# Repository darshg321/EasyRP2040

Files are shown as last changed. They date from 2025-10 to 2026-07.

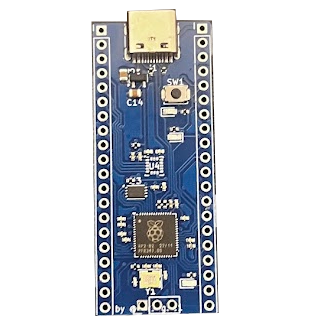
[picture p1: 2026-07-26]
BUILD.png

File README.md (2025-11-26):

# EasyRP2040.csv

my custom rp2040 devboard :)

has debug leds and a 9-DOF IMU composed of multiple 3-axis sensors

in the format of a rpi pico



# BOM

|Id |Designator|Footprint |Quantity |Comment |Supplier and ref|
|---|---|---|---|---|---|
|1  |R5,R7 |R_0402_1005Metric |2 |1K | |
|2  |C16,C15 |C_0402_1005Metric |2 |33pF | |
|3  |C10,C11,C5,C8,C3,C2,C7,C6,C4,C17,C1,C20,C18|C_0402_1005Metric |13 |0.1uF | |
|4  |D3,D1,D2  |LED_0603_1608Metric |3 |LED | |
|5  |Y1 |Crystal_SMD_3225-4Pin_3.2x2.5mm |1 |12MHz | |
|6  |R10,R9,R8 |R_0402_1005Metric |3 |680 | |
|7  |J4 |PinHeader_1x03_P2.54mm_Vertical |1 |Conn_01x03 | |
|8  |C9,C12 |C_0402_1005Metric |2 |1uF | |
|9  |U1 |QFN-56-1EP_7x7mm_P0.4mm_EP3.2x3.2mm |1 |RP2040 | |
|10 |R4,R3 |R_0402_1005Metric |2 |27 | |
|11 |U3 |Winbond_USON-8-1EP_3x2mm_P0.5mm_EP0.2x1.6mm|1 |W25Q128JVS | |
|12 |J3,J2 |PinHeader_1x20_P2.54mm_Vertical |2 |Conn_01x20 | |
|13 |C21 |C_0402_1005Metric |1 |2.2uF | |
|14 |C13,C14 |C_0201_0603Metric |2 |10uF | |
|15 |U4 |LGA-16_3x3mm_P0.5mm_LayoutBorder3x5y |1 |ICM-20602 | |
|16 |U2 |SOT-23 |1 |MCP1700x-330xxTT | |
|17 |J1 |USB_C_Receptacle_HRO_TYPE-C-31-M-12 |1 |USB_C_Receptacle_USB2.0_14P| |
|18 |SW1 |SW_Push_SPST_NO_Alps_SKRK |1 |SW_Push | |
|19 |R6 |R_0402_1005Metric |1 |10K | |
|20 |R2,R1 |R_0402_1005Metric |2 |5.1K | |
|21 |C19 |C_0402_1005Metric |1 |10nF | |

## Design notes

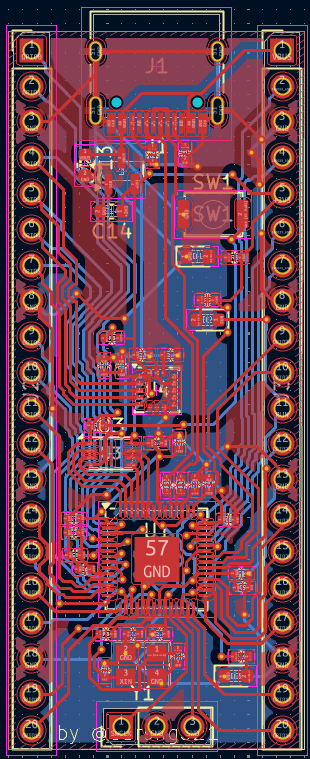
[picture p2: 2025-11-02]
EasyRP2040.png

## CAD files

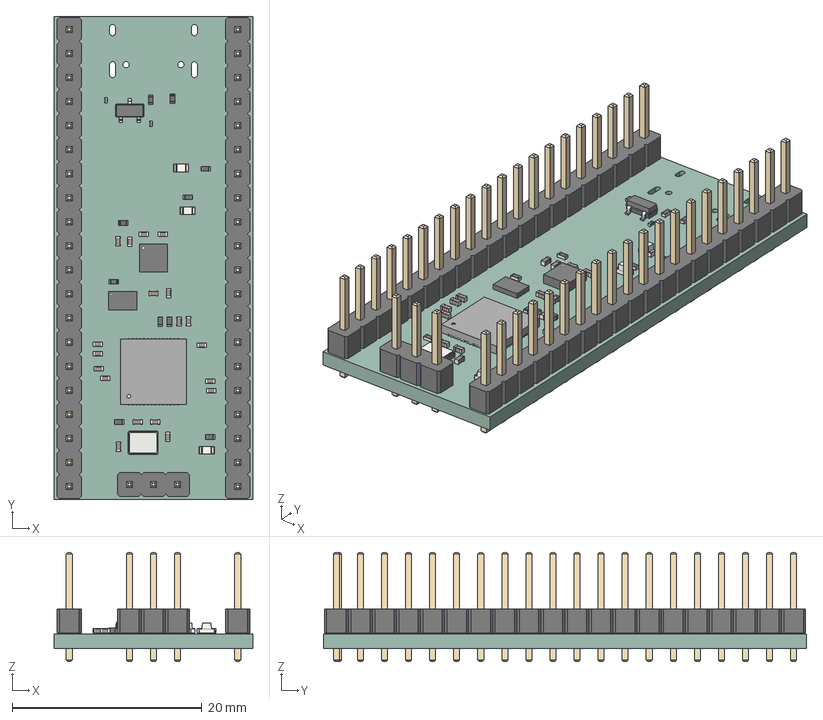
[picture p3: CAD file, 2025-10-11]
EasyRP2040.step
21.0 x 51.0 x 11.5 mm
C_0402_1005Metric x 19
PinHeader_1x20_P2.54mm_Vertical x 2
R_0402_1005Metric x 10
LED_0603_1608Metric x 3
C_0201_0603Metric x 2
LGA-16_3x3mm_P0.5mm_LayoutBorder3x5y
SOT-23
QFN-56-1EP_7x7mm_P0.4mm_EP3.2x3.2mm
Winbond_USON-8-1EP_3x2mm_P0.5mm_EP0.2x1.6mm
Crystal_SMD_3225-4Pin_3.2x2.5mm
PinHeader_1x03_P2.54mm_Vertical
EasyRP2040_PCB

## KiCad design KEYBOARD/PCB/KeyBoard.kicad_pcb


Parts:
A1: RaspberryPi_Pico; RaspberryPi_Pico_Common_Unspecified
D1, D2, D3, D4, D5, D6, D7, D8, D9, D10, D11, D12, D13, D14, D15, D16, D17, D18, D19, D20, D21, D22, D23, D24, D25, D26, D27, D28, D29, D30, D31, D32, D33, D34, D35, D36, D37, D38, D39, D40, D41, D42, D43, D44, D45, D46, D47, D48, D49, D50, D51, D52, D53, D54, D55, D56, D57, D58, D59, D60, D61: 1N4148; D_DO-35_SOD27_P7.62mm_Horizontal
S1: MX_stab; STAB_MX_2u
S2, S3: MX_stab; STAB_MX_2.25u
S4: MX_stab; STAB_MX_2.75u
S5: MX_stab; STAB_MX_6.25u
SW1, SW2, SW3, SW4, SW5, SW6, SW7, SW8, SW9, SW10, SW11, SW12, SW13, SW16, SW17, SW18, SW19, SW20, SW21, SW22, SW23, SW24, SW25, SW26, SW27, SW30, SW31, SW32, SW33, SW34, SW35, SW36, SW37, SW38, SW39, SW40, SW51, SW52, SW53, SW54, SW55, SW56, SW57, SW58, SW59, SW60: SW_Push; SW_Cherry_MX_1.00u_PCB
SW14: SW_Push; SW_Cherry_MX_2.00u_PCB
SW15: SW_Push; SW_Cherry_MX_1.50u_PCB
SW28: SW_Push; SW_Cherry_MX_1.50u_Plate
SW29: SW_Push; SW_Cherry_MX_1.75u_PCB
SW41, SW50: SW_Push; SW_Cherry_MX_2.25u_PCB
SW42, SW43, SW44, SW46, SW48, SW49: SW_Push; SW_Cherry_MX_1.25u_PCB
SW45: SW_Push; SW_Cherry_MX_6.25u_PCB
SW47: SW_Push; SW_Cherry_MX_1.25u_Plate
SW61: SW_Push; SW_Cherry_MX_2.75u_PCB
SW62, SW63: RotaryEncoder_Switch_MP; RotaryEncoder_Alps_EC11E-Switch_Vertical_H20mm

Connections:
A1: A1.27 (GPIO21), SW62.A
A2: A1.32 (GPIO27_ADC1), SW63.A
B1: A1.29 (GPIO22), SW62.B
B2: A1.34 (GPIO28_ADC2), SW63.B
C0: A1.10 (GPIO7), SW1.1, SW15.1, SW29.1, SW42.1, SW50.1
C1: A1.11 (GPIO8), SW2.1, SW16.1, SW30.1, SW43.1, SW51.1
C2: A1.12 (GPIO9), SW3.1, SW17.1, SW31.1, SW44.1, SW52.1
C3: A1.14 (GPIO10), SW4.1, SW18.1, SW32.1, SW53.1
C4: A1.15 (GPIO11), SW5.1, SW19.1, SW33.1, SW54.1
C5: A1.16 (GPIO12), SW6.1, SW20.1, SW34.1, SW45.1, SW55.1
C6: A1.17 (GPIO13), SW7.1, SW21.1, SW35.1, SW56.1
C7: A1.19 (GPIO14), SW8.1, SW22.1, SW36.1, SW57.1
C8: A1.20 (GPIO15), SW9.1, SW23.1, SW37.1, SW46.1, SW58.1
C9: A1.21 (GPIO16), SW10.1, SW24.1, SW38.1, SW47.1, SW59.1
C10: A1.22 (GPIO17), SW11.1, SW25.1, SW39.1, SW48.1, SW60.1
C11: A1.24 (GPIO18), SW12.1, SW26.1, SW40.1, SW49.1, SW61.1
C12: A1.25 (GPIO19), SW13.1, SW27.1, SW41.1
C13: A1.26 (GPIO20), SW14.1, SW28.1
GND: A1.33 (AGND), SW62.C, SW62.S2, SW63.C, SW63.S2
unnamed: A1.3 (GND), A1.8 (GND), A1.13 (GND), A1.18 (GND), A1.23 (GND), A1.28 (GND), A1.38 (GND)
unnamed: D1.2 (A), SW1.2
unnamed: D2.2 (A), SW2.2
unnamed: D3.2 (A), SW3.2
unnamed: D4.2 (A), SW4.2
unnamed: D5.2 (A), SW5.2
unnamed: D6.2 (A), SW6.2
unnamed: D7.2 (A), SW7.2
unnamed: D8.2 (A), SW8.2
unnamed: D9.2 (A), SW9.2
unnamed: D10.2 (A), SW10.2
unnamed: D11.2 (A), SW11.2
unnamed: D12.2 (A), SW12.2
unnamed: D13.2 (A), SW13.2
unnamed: D14.2 (A), SW14.2
unnamed: D15.2 (A), SW15.2
unnamed: D16.2 (A), SW16.2
unnamed: D17.2 (A), SW17.2
unnamed: D18.2 (A), SW18.2
unnamed: D19.2 (A), SW19.2
unnamed: D20.2 (A), SW20.2
unnamed: D21.2 (A), SW21.2
unnamed: D22.2 (A), SW22.2
unnamed: D23.2 (A), SW23.2
unnamed: D24.2 (A), SW24.2
unnamed: D25.2 (A), SW25.2
unnamed: D26.2 (A), SW26.2
unnamed: D27.2 (A), SW27.2
unnamed: D28.2 (A), SW28.2
unnamed: D29.2 (A), SW29.2
unnamed: D30.2 (A), SW30.2
unnamed: D31.2 (A), SW31.2
unnamed: D32.2 (A), SW32.2
unnamed: D33.2 (A), SW33.2
unnamed: D34.2 (A), SW34.2
unnamed: D35.2 (A), SW35.2
unnamed: D36.2 (A), SW36.2
unnamed: D37.2 (A), SW37.2
unnamed: D38.2 (A), SW38.2
unnamed: D39.2 (A), SW39.2
unnamed: D40.2 (A), SW40.2
unnamed: D41.2 (A), SW41.2
unnamed: D42.2 (A), SW42.2
unnamed: D43.2 (A), SW43.2
unnamed: D44.2 (A), SW44.2
unnamed: D45.2 (A), SW45.2
unnamed: D46.2 (A), SW46.2
unnamed: D47.2 (A), SW47.2
unnamed: D48.2 (A), SW48.2
unnamed: D49.2 (A), SW49.2
unnamed: D50.2 (A), SW50.2
unnamed: D51.2 (A), SW51.2
unnamed: D52.2 (A), SW52.2
unnamed: D53.2 (A), SW53.2
unnamed: D54.2 (A), SW54.2
unnamed: D55.2 (A), SW55.2
unnamed: D56.2 (A), SW56.2
unnamed: D57.2 (A), SW57.2
unnamed: D58.2 (A), SW58.2
unnamed: D59.2 (A), SW59.2
unnamed: D60.2 (A), SW60.2
unnamed: D61.2 (A), SW61.2
R0: A1.4 (GPIO2), D1.1 (K), D2.1 (K), D3.1 (K), D4.1 (K), D5.1 (K), D6.1 (K), D7.1 (K), D8.1 (K), D9.1 (K), D10.1 (K), D11.1 (K), D12.1 (K), D13.1 (K), D14.1 (K)
R1: A1.5 (GPIO3), D15.1 (K), D16.1 (K), D17.1 (K), D18.1 (K), D19.1 (K), D20.1 (K), D21.1 (K), D22.1 (K), D23.1 (K), D24.1 (K), D25.1 (K), D26.1 (K), D27.1 (K), D28.1 (K)
R2: A1.6 (GPIO4), D29.1 (K), D30.1 (K), D31.1 (K), D32.1 (K), D33.1 (K), D34.1 (K), D35.1 (K), D36.1 (K), D37.1 (K), D38.1 (K), D39.1 (K), D40.1 (K), D41.1 (K)
R3: A1.7 (GPIO5), D50.1 (K), D51.1 (K), D52.1 (K), D53.1 (K), D54.1 (K), D55.1 (K), D56.1 (K), D57.1 (K), D58.1 (K), D59.1 (K), D60.1 (K), D61.1 (K)
R4: A1.9 (GPIO6), D42.1 (K), D43.1 (K), D44.1 (K), D45.1 (K), D46.1 (K), D47.1 (K), D48.1 (K), D49.1 (K)
S1: A1.31 (GPIO26_ADC0), SW62.S1
S2: A1.2 (GPIO1), SW63.S1



Board: 2 copper layers, 321.0 x 101.0 mm, 130 parts (61 on the bottom side), 88 nets.

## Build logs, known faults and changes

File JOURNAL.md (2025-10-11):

<!--
  ===================    !!READ THIS NOTICE!!   ====================
  DO NOT edit this file manually. Your changes WILL BE OVERWRITTEN!
  This journal is auto generated and updated by Hack Club Blueprint.
  To edit this file, please edit your journal entries on Blueprint.
  ==================================================================
-->

This is my journal of the design and building process of **EasyRP2040**.  
You can view this journal in more detail on **Hack Club Blueprint** [here](https://blueprint.hackclub.com/projects/391).

## 10/10/2025 4 PM - finished the schamtic !  

finished the schematic for the devboard

notes on learning:

- decoupling capacitors filter out noise in power; 0.1uF for the each power pin (theres multiple in reality, kicad just merges the same ones together), and 1uF for each power line
- shield is the metal conductive part on the usb, connects to gnd to improve EMI (electromagnetic interference)
- 10uF bulk capacitors to filter out significant noise when 5v is stepped down to 3v3, both on input and output
- usb dp and dm go through 27ohm resistors to prevent distortion at high data speed, called termination resistors
- crystal oscillator: vibrating quartz crystal, amplified and fed to the MCU, this acts as a clock for all the other digital peripherals
- important here bc using usb c; data needs to come in at very specific times
- needs to be physically very close to the MCU
- XIN: output from crystal to MCU
- XOUT: output from MCU to crystal to control
- damping resistor to XOUT for signal integrity
- series capacitors (external load) for crystal to resonate at correct frequency
- SPI pins: MOSI (master output), MISO (master input), SCLK (crystal oscillator timing), SS/CS (device selection, add more of these for more devices)
- using quad SPI with this, but has 4 IO for 4x data transferring
- needs to be connected to the dedicated hardware controller (QSPI) on the MCU
- booting: if QSPI SS is GND when booting up, it goes into BOOTSEL, which is when it appears as a usb device
- done by adding a pull up resistor (guarantee HIGH when booting) to 3v3, and a resistor (limit current to pin) to a button that goes to GND

Screenshot 2025-10-10 165033.png

## 10/10/2025 7 PM - added imu + leds for customization  

added the icm-20602 imu on the devboard; picked it bc its the simplest one that jlcpcb has. it requires two capacitors on vdd for some reason, and one other one on vddio. also added leds, one is a power led (will be green), one is a bootloader led which hopefully going through RUN should only be on when the devboard is in BOOTSEL, and one last one thats just connected to gpio25 bc its unused.
Screenshot 2025-10-10 190902.png  

## 10/10/2025 10 PM - partially routed pcb  

added footprints to everything, and partially routed the pcb. i have the rough shape of everything there, and roughly where everything is supposed to go. learned that you need to do differential pairs, and that the usb lines need to be the same length so that data travel at the same exact rate
Screenshot 2025-10-10 224958.png

## 10/11/2025 1 AM - more routing...  

this takes forever aaaa
routed more of the pcb, started the gnd plane which didnt do much bc my routing was very bad, separated a whole bunch of gnd pins. need to fix a lot of routing bc i have a bunch of bottom and top traces so i cant pass gnd through it :(
Screenshot 2025-10-11 010821.png  

## 10/11/2025 4 PM - finished routing the pcb  

finished routing the pcb; took forever to fix my routing but oh well.
lessons learned: 
- do ics first
- do capacitors after that
- minimize vias and non gnd back signals better
i have some thermal via issues but that isnt a big problem, especially single im doing pcba as well
Screenshot 2025-10-11 163931.png

## 10/11/2025 7 PM - added to jlcpcb cart  

took forever too but finished making the prod files and fixing everything on jlcpcb

unfortunately the imu i put is standard only, and that adds like $50, so ill buy it and place it myself since i have solder paste and a hot gun

also drew silkscreen stuff which i didnt mention; made it on excalidraw i think it looks cute :)
done yippee



Screenshot 2025-10-11 192141.png

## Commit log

2025-10-10 finished schematic
    [EasyRP2040.kicad_sch]
2025-10-10 added imu + leds to schematic
    [EasyRP2040.kicad_sch]
2025-10-22 fixed c13 c14
    [EasyRP2040.kicad_sch, JLCPCB BOM.xls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]
